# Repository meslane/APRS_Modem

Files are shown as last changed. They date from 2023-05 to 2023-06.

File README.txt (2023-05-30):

  _       _     _ _ _     _      _     _    _     _ _ _
/\_\    /\_\  /\_\_\_\  /\_\ _ /\_\  /\_\ /\_\  /\_\_\_\
\/\_\   \ \_\ \/\_\/_/_ \/\_\_\\_\_\ \/\_\__\_\ \/\_\/\_\
 \/\_\  _\ \_\ \/\_\_\_\ \/\_\//\_\_\ \/_/_\_\/_ \/\_\_\_\
  \/\_\/\_\_\_\ \/\_\/\_\ \/\_\\/_/\_\  /\ \_/\ \ \/\_\/_/
   \/\_\_\_\_\_\ \/\_\_\_\ \/\_\  \/\_\ \/\_\\/\_\ \/\_\ 
    \/_/_/_/_/_/  \/_/_/_/  \/_/   \/_/  \/_/ \/_/  \/_/
    
 ##   ###   ###    ###    #   #   ##   ###   ####  #   #  #
#  #  #  #  #  #  #       ## ##  #  #  #  #  #     ## ##  #
####  ###   ###    ##     # # #  #  #  #  #  ####  # # #  #
#  #  #     # #      #    #   #  #  #  #  #  #     #   #  
#  #  #     #  #  ###     #   #   ##   ###   ####  #   #  #

~== Current Functionality ==~
-Encoding and transmission of arbitrary packets over resistor DAC
-Automatic radio push-to-talk activation
-GPS module support
-LCD + rotart encoder user interface
-Persistent settings
-TX jitter setting
-RX capabilites + decoding + CRC checking
-Python TX/RX script

~== Tips and Tricks ==~
-Make sure you're not over/under-driving the output of the transmit circuit.
 Over/under modulation can cause a reciever to fail to properly decode packets.
 You should test this with a second radio and the python demodulation script included here
-Also check reciever volume into your PC for the same reasons
 The demodulator is more resistant to distortion than noise, but it can't hurt

~== Current Bugs (TOFIX) ==~
-AGC on the reciever looks like it may require a longer start/stop flag to lock on
	-Will need to test further though

~== Acknowlegements ==~
-Cal EE123 (packet formatting info): https://inst.eecs.berkeley.edu/~ee123/sp15/lab/lab6/Lab6_Part_B-APRS.html
-Matthew Tran (verification code): https://matthewtran.dev/
-UCR CS120B for LCD code
-Mark Adler on StackOverflow for CRC function code

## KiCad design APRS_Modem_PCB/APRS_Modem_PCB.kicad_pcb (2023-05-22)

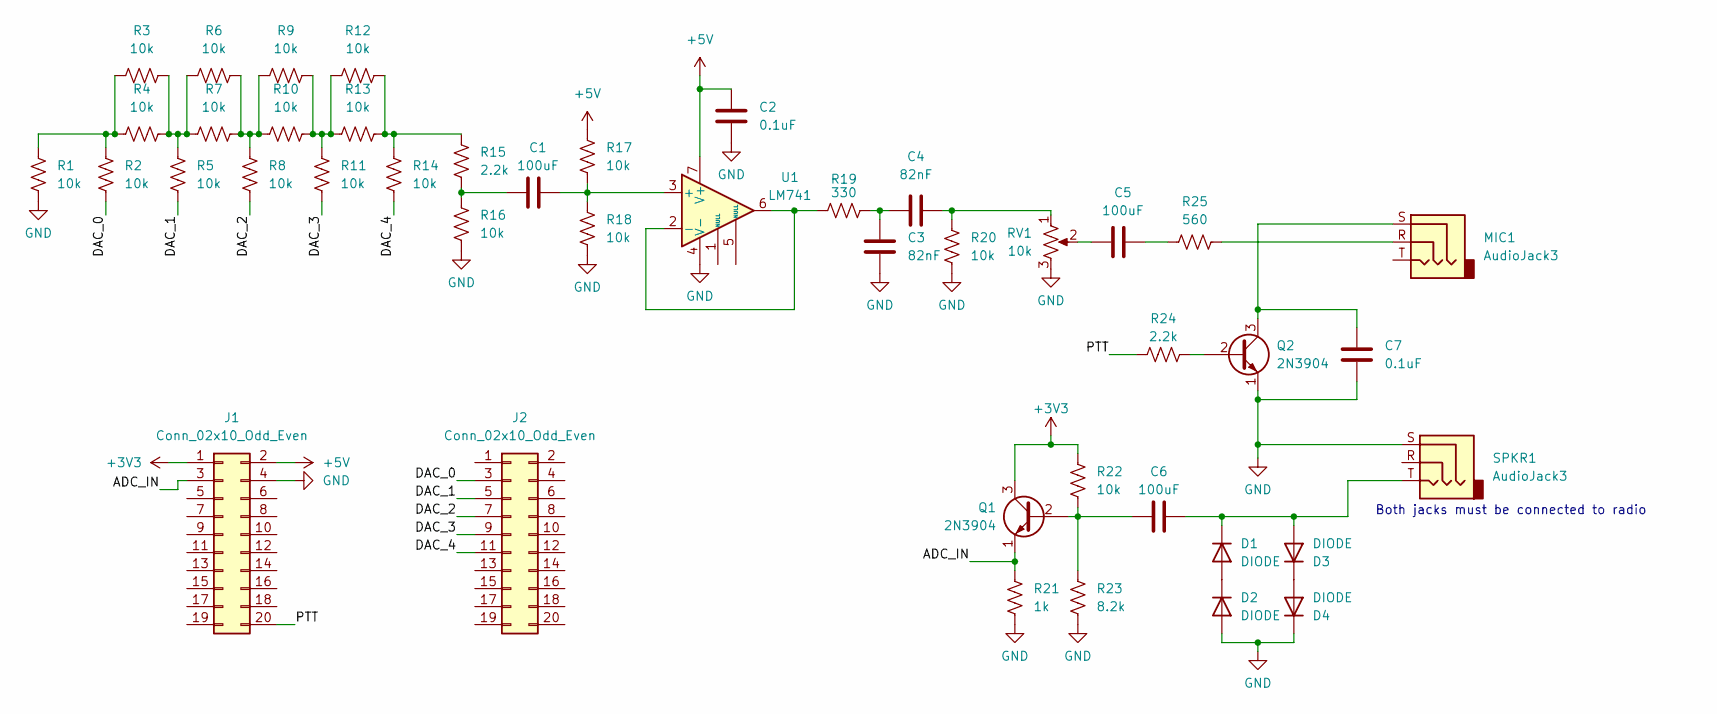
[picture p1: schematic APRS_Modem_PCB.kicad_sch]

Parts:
C1, C5, C6: 100uF; CP_Radial_D8.0mm_P3.80mm
C2, C7: 0.1uF; C_Disc_D4.3mm_W1.9mm_P5.00mm
C3, C4: 82nF; C_Disc_D4.3mm_W1.9mm_P5.00mm
D1, D2, D3, D4: DIODE; D_A-405_P7.62mm_Horizontal
J1, J2: Conn_02x10_Odd_Even; PinHeader_2x10_P2.54mm_Vertical
MIC1: AudioJack3; Jack_3.5mm_CUI_SJ1-3525N_Horizontal
Q1, Q2: 2N3904; TO-92_Inline
R1, R3, R4, R6, R7, R9, R10, R12, R13: 10k; R_Axial_DIN0207_L6.3mm_D2.5mm_P5.08mm_Vertical
R2, R5, R8, R11, R14, R16, R17, R18, R20, R22: 10k; R_Axial_DIN0207_L6.3mm_D2.5mm_P10.16mm_Horizontal
R15, R24: 2.2k; R_Axial_DIN0207_L6.3mm_D2.5mm_P10.16mm_Horizontal
R19: 330; R_Axial_DIN0207_L6.3mm_D2.5mm_P10.16mm_Horizontal
R21: 1k; R_Axial_DIN0207_L6.3mm_D2.5mm_P10.16mm_Horizontal
R23: 8.2k; R_Axial_DIN0207_L6.3mm_D2.5mm_P10.16mm_Horizontal
R25: 560; R_Axial_DIN0207_L6.3mm_D2.5mm_P10.16mm_Horizontal
RV1: 10k; Potentiometer_Alpha_RD901F-40-00D_Single_Vertical
SPKR1: AudioJack3; Jack_3.5mm_CUI_SJ1-3525N_Horizontal
U1: LM741; DIP-8_W7.62mm_LongPads

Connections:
+3V3: J1.1, Q1.3 (C), R22.1
+5V: C2.1, J1.2, R17.1, U1.7 (V+)
/ADC_IN: J1.3, Q1.1 (E), R21.1
/DAC_0: J2.3, R2.2
/DAC_1: J2.5, R5.2
/DAC_2: J2.7, R8.2
/DAC_3: J2.9, R11.2
/DAC_4: J2.11, R14.2
/PTT: J1.20, R24.1
GND: C2.2, C3.2, C7.2, D2.1 (A), D4.2 (K), J1.4, Q2.1 (E), R1.2, R16.2, R18.2, R20.2, R21.2, R23.2, RV1.3, SPKR1.S, U1.4 (V-)
unnamed: C1.1, R15.2, R16.1
unnamed: C1.2, R17.2, R18.1, U1.3 (+)
unnamed: D1.1 (A), D2.2 (K)
unnamed: C6.2, D1.2 (K), D3.1 (A), SPKR1.T
unnamed: D3.2 (K), D4.1 (A)
unnamed: MIC1.R, R25.2
unnamed: C7.1, MIC1.S, Q2.3 (C)
unnamed: C6.1, Q1.2 (B), R22.2, R23.1
unnamed: Q2.2 (B), R24.2
unnamed: R1.1, R2.1, R3.1, R4.1
unnamed: R3.2, R4.2, R5.1, R6.1, R7.1
unnamed: R6.2, R7.2, R8.1, R9.1, R10.1
unnamed: R9.2, R10.2, R11.1, R12.1, R13.1
unnamed: R12.2, R13.2, R14.1, R15.1
unnamed: C3.1, C4.1, R19.2
unnamed: C4.2, R20.1, RV1.1
unnamed: C5.2, R25.1
unnamed: C5.1, RV1.2
unnamed: R19.1, U1.2 (-), U1.6

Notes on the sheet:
Both jacks must be connected to radio

Board: 2 copper layers, 44 parts (0 on the bottom side), 29 nets, no tracks yet.

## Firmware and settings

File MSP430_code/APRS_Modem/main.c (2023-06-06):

#include <msp430.h> 

#include <serial.h>
#include <dsp.h>
#include <math.h>
#include <packet.h>
#include <gps.h>
#include <ui.h>
#include <bbs.h>

char message[MAX_PACKET];

#pragma PERSISTENT(msg)
struct message msg = {.num_callsigns = 0,
                     .payload_len = 0,
                     .crc = CRC_FAIL};


struct message outgoing_message;

#pragma PERSISTENT(temp_msg) //need this to avoid memory fuckery
struct message temp_msg = {.num_callsigns = 0,
                           .payload_len = 0,
                           .crc = CRC_FAIL};

char* BBS_CALL = "BBS-1";

struct TicTacToe ttt_game;

enum RX_state{RX_START, RX_UNLOCKED, RX_START_FLAG, RX_MESSAGE, RX_END_FLAG, RX_DECODE, RX_RESET};
enum RX_state RX_tick(enum RX_state state) {
    static long flag_queue = 0xFFFFFFFF;
    static unsigned char bit_index = 0;
    static char byte = 0x01; //data byte grabbed from routine
    static unsigned int message_index = 0;

    /* transitions */
    switch(state) {
    case RX_START:
        state = RX_UNLOCKED;
        break;
    case RX_UNLOCKED:
        if (flag_queue == 0x01010101) { //consistent start flag
            //flag_queue = 0xFFFFFFFF; //reset for next cycle
            state = RX_START_FLAG;
            putchars("LOCK\n\r");
        }
        break;
    case RX_START_FLAG:
        if (bit_index == 0 && byte != 0x01) { //if no longer getting start flags
            state = RX_MESSAGE;
            putchars("MSG\n\r");
        }
        break;
    case RX_MESSAGE:
        if ((flag_queue & 0x000000FF) == 0x01 || (flag_queue & 0x000000FF) == 0x7F) { //detect end flag
            if (bit_index == 0 && (flag_queue & 0x000000FF) == 0x7F) {
                message[message_index] = 0x00;
                message_index++; //add extra byte
            }

            state = RX_END_FLAG;
            putchars("END\n\r");
        } else if (message_index >= MAX_PACKET || (bit_index == 0 && byte == 0x00)) { //if overflow message buffer or bad packet data
            state = RX_RESET;
            putchars("FAILED\n\r");
        }
        break;
    case RX_END_FLAG:
        if (num_ones(flag_queue, 8) != 1 && num_ones(flag_queue, 8) != 7) { //if end flags are over
            state = RX_DECODE; //go to decode now that end flags are done
            putchars("UNLOCK\n\r");
        }
        break;
    case RX_DECODE:
        state = RX_RESET;
        break;
    case RX_RESET:
        state = RX_UNLOCKED;
        break;
    default:
        state = RX_START;
        break;
    }

    /* actions */
    switch(state) {
    case RX_UNLOCKED:
        //P1OUT &= ~(0x01 << 2); //DEBUG

        if (rx_ready == 1) { //if PLL has triggered a bit sample
            rx_ready = 0;

            flag_queue = ((flag_queue << 1) & 0xFFFFFFFE) | rx_bit; //shift flag queue and add RX bit to end
        }
        break;
    case RX_START_FLAG:
    case RX_MESSAGE:
    case RX_END_FLAG:
        //P1OUT |= (0x01 << 2); //DEBUG

        if (rx_ready == 1) { //if PLL has triggered a bit sample
            rx_ready = 0;

            if (bit_index == 0) {
                if (state == RX_MESSAGE) {
                    message[message_index] = byte;
                    message_index++;
                }

                byte = 0;
            }

            byte |= (rx_bit << (7 - bit_index));

            bit_index = (bit_index < 7) ? bit_index + 1 : 0; //increment if less than 7, otherwise reset

            flag_queue = ((flag_queue << 1) & 0xFFFFFFFE) | rx_bit; //do flag queue
        }
        break;
    case RX_DECODE:
        //P1OUT |= (0x01 << 2); //DEBUG

        enable_FRAM_write(FRAM_WRITE_ENABLE);
        msg = demod_AX_25_packet_to_msg(message, message_index);
        enable_FRAM_write(FRAM_WRITE_DISABLE);
        print_message_packet(&msg);
        break;
    case RX_RESET:
        //P1OUT |= (0x01 << 2); //DEBUG

        message_index = 0; //reset for next pass
        bit_index = 0;
        byte = 0x01; //so it doesn't immediately go to message
        break;
    default:
        break;
    }

    return state;
}

enum BBS_state{BBS_START, BBS_RX, BBS_PROCESS, BBS_TX};
enum BBS_state BBS_tick(enum BBS_state state) {
    static enum RX_state rx_state = RX_START;

    static char temp[128];
    unsigned int i;
    unsigned int j;
    static char num_temp[4];
    unsigned int stack_size;
    unsigned int msg_id;
    char game_state;
    static char substring[12];

    /* transitions */
    switch (state) {
    case BBS_START:
        init_DSP_timer(DSP_RX);
        enable_DSP_timer();
        state = BBS_RX;
        break;
    case BBS_RX:
        if (rx_state == RX_DECODE) { //if a message has been gotten, process it
            disable_DSP_timer(); //pause DSP
            state = BBS_PROCESS;
        }
        break;
    case BBS_PROCESS:
        if (streq(msg.callsigns[0], "BBS-1", 5) || streq(msg.callsigns[2], "BBS-1", 5)) { //if message is made out to BBS or BBS is a repeater
            init_DSP_timer(DSP_TX);
            state = BBS_TX;
        } else {
            init_DSP_timer(DSP_RX);
            enable_DSP_timer();
            state = BBS_RX;
        }
        break;
    case BBS_TX:
        init_DSP_timer(DSP_RX);
        enable_DSP_timer();
        state = BBS_RX;
        break;
    default:
        state = BBS_START;
        break;
    }

    /* actions */
    switch (state) {
    case BBS_START:
        break;
    case BBS_RX:
        rx_state = RX_tick(rx_state); //increment RX state machine in RX mode
        break;
    case BBS_PROCESS:
        /* MAIN BBS work code */
        if (streq(msg.callsigns[0], "BBS-1", 5)) { //direct commands to the sever
            strcpy(outgoing_message.callsigns[0], msg.callsigns[1], 10); //move sender to recipient
            strcpy(outgoing_message.callsigns[1], BBS_CALL, 10);
            strcpy(outgoing_message.callsigns[2], msg.callsigns[2], 10);
            outgoing_message.num_callsigns = 3;

            if (streq(msg.payload, "!ping", 5)) {
                strcpy(outgoing_message.payload, "pong!", MAX_PAYLOAD);
            }
            else if (streq(msg.payload, "!help", 5)) {
                strcpy(outgoing_message.payload, "Commands: !ping, !help, !users, !messages, !message, !delete, !ttt (!about [command] for more info)", MAX_PAYLOAD);
            }
            else if (streq(msg.payload, "!about ping", 11)) {
                strcpy(outgoing_message.payload, "!ping: pings the server, server responds with '!pong' if message was received", MAX_PAYLOAD);
            }
            else if (streq(msg.payload, "!about help", 11)) {
                strcpy(outgoing_message.payload, "!help: lists all commands", MAX_PAYLOAD);
            }
            else if (streq(msg.payload, "!about users", 12)) {
                strcpy(outgoing_message.payload, "!users: lists all users whose messages are currently stored on the server", MAX_PAYLOAD);
            }
            else if (streq(msg.payload, "!about messages", 15)) {
                strcpy(outgoing_message.payload, "!messages: returns the number of stored messages addressed to the user", MAX_PAYLOAD);
            }
            else if (streq(msg.payload, "!about message", 14)) {
                strcpy(outgoing_message.payload, "!message [number]: returns the requested message addressed to the user (if it exists)", MAX_PAYLOAD);
            }
            else if (streq(msg.payload, "!about delete", 13)) {
                strcpy(outgoing_message.payload, "!delete [number]: deletes the given message addressed to the user (do this after reading, oldest messages are auto-deleted)", MAX_PAYLOAD);
            }
            else if (streq(msg.payload, "!about ttt", 10)) {
                strcpy(outgoing_message.payload, "!ttt [move]: plays the given tic-tac-toe move (assuming move is valid and game is not occupied)", MAX_PAYLOAD);
            }
            else if (streq(msg.payload, "!users", 6)) {
                temp[0] = '\0';
                strcat(temp, "Users:");

                for (i = 0; i < message_stack_size(); i++) {
                    strcpy(substring, peek_message_stack(i).callsigns[1], 10);
                    strcat(substring, " "); //must append space to avoid false positives

                    if (instr(temp, substring) == 0) {
                        strcat(temp, peek_message_stack(i).callsigns[1]); //append sender
                        strcat(temp, " "); //append space
                    }
                }

                strcpy(outgoing_message.payload, temp, MAX_PAYLOAD);
            }
            else if (streq(msg.payload, "!messages", 9)) {
                temp[0] = '\0';
                strcat(temp, "Message IDs stored for you = ");

                stack_size = message_stack_size();
                for (i = 0; i < stack_size; i++) {
                    enable_FRAM_write(FRAM_WRITE_ENABLE);
                    temp_msg = peek_message_stack(i);
                    enable_FRAM_write(FRAM_WRITE_DISABLE);

                    if (streq(temp_msg.callsigns[0], msg.callsigns[1], 9)) { //if addressed to user
                        int_to_str(num_temp, i, 2);
                        strcat(temp, num_temp);
                        strcat(temp, " ");
                    }
                }

                strcpy(outgoing_message.payload, temp, MAX_PAYLOAD);
            }
            else if (streq(msg.payload, "!message", 8)) {
                temp[0] = '\0';
                msg_id = str_to_int(&msg.payload[9]);

                stack_size = message_stack_size();
                if (msg_id >= stack_size) {
                    strcat(temp, "ERROR: message ID out of range");
                } else {
                    enable_FRAM_write(FRAM_WRITE_ENABLE);
                    temp_msg = peek_message_stack(i);
                    enable_FRAM_write(FRAM_WRITE_DISABLE);

                    if (streq(temp_msg.callsigns[0], msg.callsigns[1], 9)) {
                        strcat(temp, temp_msg.payload);

                        for (j = 0; j < temp_msg.num_callsigns; j++) {
                            strcpy(outgoing_message.callsigns[j], temp_msg.callsigns[j], 10);
                        }
                        outgoing_message.num_callsigns = temp_msg.num_callsigns;
                    } else {
                        strcat(temp, "ERROR: message is not addressed to you");
                    }
                }
                strcpy(outgoing_message.payload, temp, MAX_PAYLOAD);
            }
            else if (streq(msg.payload, "!delete", 7)) {
                temp[0] = '\0';
                msg_id = str_to_int(&msg.payload[8]);

                stack_size = message_stack_size();
                if (msg_id >= stack_size) {
                    strcat(temp, "ERROR: message ID out of range");
                } else {
                    enable_FRAM_write(FRAM_WRITE_ENABLE);
                    temp_msg = peek_message_stack(i);
                    enable_FRAM_write(FRAM_WRITE_DISABLE);

                    if (streq(temp_msg.callsigns[0], msg.callsigns[1], 9)) {
                        pop_message(msg_id);
                        strcat(temp, "Deleted message");
                    } else {
                        strcat(temp, "ERROR: message is not addressed to you");
                    }
                }
                strcpy(outgoing_message.payload, temp, MAX_PAYLOAD);
            }
            else if (streq(msg.payload, "!ttt", 4)) {
                temp[0] = '\0';

                if (ttt_game.finished == 1) { //init game
                    init_board(&ttt_game);
                }

                if (strlen(msg.payload) >= 7) { //only do game if move, otherwise just peek board
                    if (ttt_game.P1_call[0] == '\0') { //assign players
                        strcpy(ttt_game.P1_call, msg.callsigns[1], 10);
                    }
                    else if (ttt_game.P2_call[0] == '\0') {
                        if (streq(ttt_game.P1_call, msg.callsigns[1], 10) == 0) { //don't let players play against themselves
                            strcpy(ttt_game.P2_call, msg.callsigns[1], 10);
                        }
                    }

                    if (ttt_game.player_turn == 1 && streq(ttt_game.P1_call, msg.callsigns[1], 10)) { //player 1 turn
                        if (process_move(&ttt_game, &msg.payload[5], 1) == 1) {
                            ttt_game.player_turn = 2;
                        }
                        update_game_board(&ttt_game);
                    } else if (ttt_game.player_turn == 2 && streq(ttt_game.P2_call, msg.callsigns[1], 10)) { //player 2 turn
                        if (process_move(&ttt_game, &msg.payload[5], 2) == 1) {
                            ttt_game.player_turn = 1;
                        }
                        update_game_board(&ttt_game);
                    }
                }

                strcat(temp, ttt_game.board);
                strcat(temp, "\nX:");
                strcat(temp, ttt_game.P1_call);
                strcat(temp, " O:");
                strcat(temp, ttt_game.P2_call);
                strcat(temp, "\nNext:");
                if (ttt_game.player_turn == 1) {
                    strcat(temp, "X");
                } else if (ttt_game.player_turn == 2) {
                    strcat(temp, "O");
                }


                game_state = detect_end_condition(&ttt_game);
                if (game_state != 0) {
                    strcat(temp, "\n");

                    if (game_state == 1) {
                        strcat(temp, ttt_game.P1_call);
                        strcat(temp, " wins!");
                    } else if (game_state == 2) {
                        strcat(temp, ttt_game.P2_call);
                        strcat(temp, " wins!");
                    } else {
                        strcat(temp, "Tie game");
                    }

                    ttt_game.finished = 1;
                }

                strcpy(outgoing_message.payload, temp, MAX_PAYLOAD);
            }
            else {
                strcpy(outgoing_message.payload, "Invalid command (send '!help' for list)", MAX_PAYLOAD);
            }
        }
        else if (streq(msg.callsigns[2], "BBS-1", 5)) { //forwards to other users
            push_message(msg);

            strcpy(outgoing_message.callsigns[0], msg.callsigns[1], 10); //move sender to recipient
            strcpy(outgoing_message.callsigns[1], BBS_CALL, 10);
            strcpy(outgoing_message.callsigns[2], "\0", 1); //no repeaters
            outgoing_message.num_callsigns = 2;

            strcpy(outgoing_message.payload, "Saved message to be forwarded", MAX_PAYLOAD);
        }
        break;
    case BBS_TX:
        send_message(&outgoing_message);
        break;
    default:
        break;
    }

    return state;
}

int main(void) {
    WDTCTL = WDTPW | WDTHOLD;   //stop watchdog timer
    PM5CTL0 &= ~LOCKLPM5; //disable high-impedance GPIO mode
    __bis_SR_register(GIE); //enable interrupts

    Software_Trim();
    init_clock();
    init_UART_UCA1(115200); //terminal output

    //set P1.5 to ADC input
    P1SEL0 |= (1 << 5);
    P1SEL1 |= (1 << 5);
    init_ADC(5); //init for channel #5

    P1DIR |= (0x01 << 4);
    P1DIR |= (0x01 << 1);
    P1DIR |= (0x01 << 3);
    P1DIR |= (0x01 << 2);

    enum BBS_state bbs_state = BBS_START;

    unsigned long long tick = 0;
    init_resistor_DAC();
    init_PTT();

    ttt_game.finished = 1;

    putchars("\n\r");

    for(;;) {
        bbs_state = BBS_tick(bbs_state);
        tick++;
    }

    return 0;
}

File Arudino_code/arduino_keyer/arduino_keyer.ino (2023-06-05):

//I normally look down upon using Arduino at a college level
//I mainly chose to use it here because I needed something quick and dirty that fit on a half size breadboard
//Also, look how simple this code is

#define KEYER_PIN 2

void setup() {
  Serial.begin(9600);
  pinMode(KEYER_PIN, OUTPUT);
  digitalWrite(KEYER_PIN, 0); //key down
}

void loop() {
  char serial_in;

  if (Serial.available() > 0) {
    serial_in = Serial.read();
    if (serial_in == '1') {
      digitalWrite(KEYER_PIN, 1); //key up radio
    }
    else if (serial_in == '0') {
      digitalWrite(KEYER_PIN, 0); //key down
    }
  }
}

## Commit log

2023-04-16 saving just in case
2023-04-17 add README + some fixes to dsp stuff
    [dsp.c, main.c]
2023-04-18 add circuit schematics
    [APRS_Modem_Hardware.kicad_pcb, APRS_Modem_Hardware.kicad_sch]
2023-04-18 update schematic
    [APRS_Modem_Hardware.kicad_sch]
2023-04-18 refactored code + fixed packet errors
    [main.c]
2023-04-20 update readme and remove useless code
    [APRS_Modem_Hardware.kicad_sch]
2023-04-21 update readme + hopefully fix small bug
    [dsp.c]
2023-04-26 add persistent settings and jitter
    [main.c, ui.c]
2023-05-16 add fixed point and hardware multiplication to MSP430 */
    [afsk_demod.py, main.c, serial.c]
2023-05-17 improve fixed point math and update filters
    [afsk_demod.py, filter_design.py, main.c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]
2023-05-19 fixed extra byte issue and got RX CRC working
    [main.c, serial.c]
2023-05-21 start PCB schematic
    [APRS_Modem_PCB.kicad_pcb, APRS_Modem_PCB.kicad_sch]
2023-05-22 start PCB
    [APRS_Modem_PCB.kicad_pcb, APRS_Modem_PCB.kicad_sch]
2023-05-29 remove prints
2023-05-30 fixed passing CRC issue?
    [afsk_mod.py]
2023-06-05 this code doesn't work, committing to save it
    [afsk_mod.py, arduino_keyer.ino, main.c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]
2023-06-05 think the bug is it running out of RAM and not telling me
    [afsk_mod.py, main.c]
